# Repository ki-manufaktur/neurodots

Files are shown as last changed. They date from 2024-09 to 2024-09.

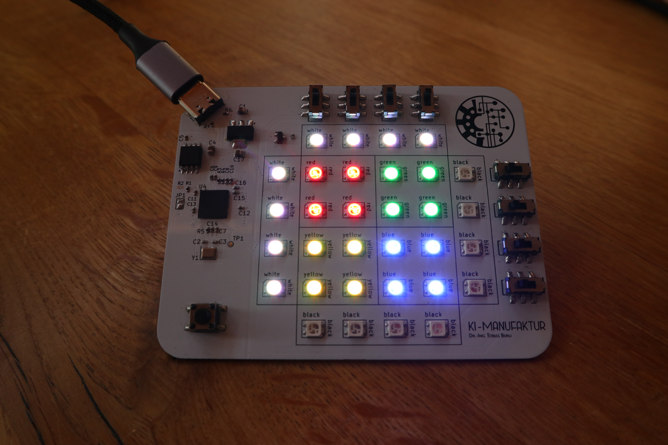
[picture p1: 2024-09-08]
doc/3.jpg

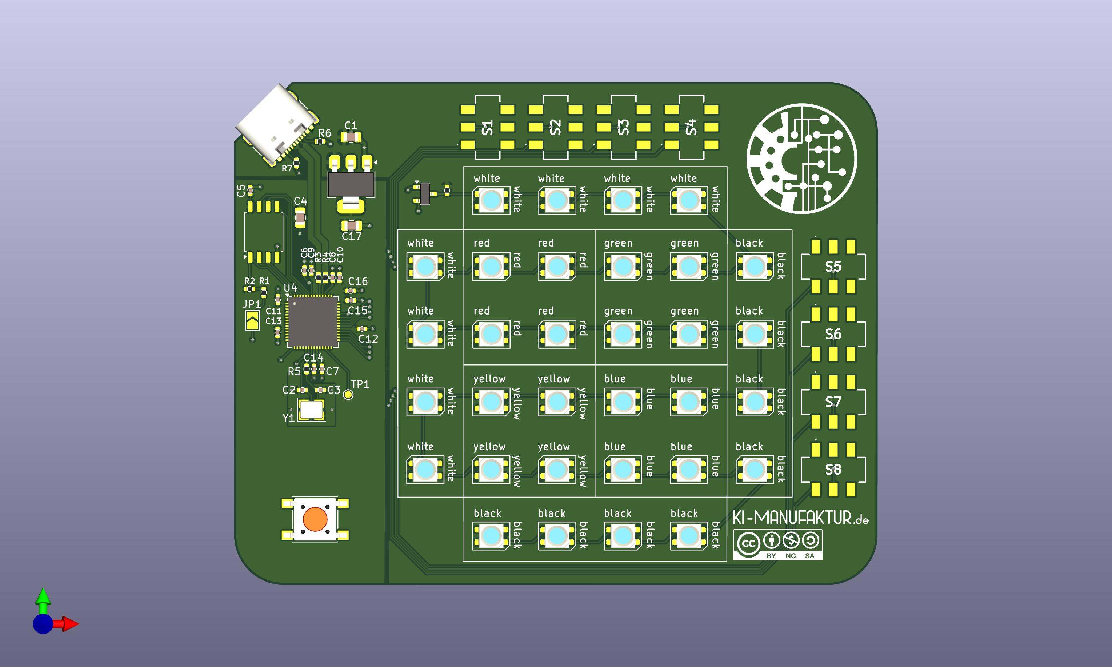
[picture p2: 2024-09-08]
doc/pcb.jpg

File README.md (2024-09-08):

# NEURODOTS

This project is inspired by the 3D printed [4x4 Colour Dot Puzzle](https://www.instructables.com/4x4-Colour-Dot-Puzzle/) by Sebastian Coddington and featured in Hackaday: [Color Dot Puzzle Will Wrinkle Your Brain](https://hackaday.com/2022/02/12/color-dot-puzzle-will-wrinkle-your-brain/).

Neurodots is an electronic version of the color dot puzzle, utilizing a WS2812 RGB maze. The dots are shifted horizontally or vertically using switches on the sides of the maze to guide the dots into the solution configuration.

In addition to the core gameplay of solving the puzzle, the project includes a feature that displays solution hints, generated by a neural network running on the RP2040 using TensorFlow Lite for Microcontrollers (TFLM). This demonstrates an intriguing application of a small neural network, as the theoretical number of possible game states is approximately 1.19e+16.

Storing a recommended move for all these states would be far beyond the storage capacity of an embedded device, even with clever compression techniques. Moreover, even if storage wasn’t an issue, determining a near-optimal move to solve the puzzle is a non-trivial task. This challenge also applies to heuristic algorithms running on the device.

Thus, the training objective of the neural network was to find a policy that solves the puzzle using the minimum number of moves. By quantizing and deploying this model in the TFLM environment, solutions are generated in real-time, with a response time of approximately 1.4 seconds from state change to recommendation.

## Usage

https://github.com/user-attachments/assets/8f202e22-c553-46a4-99aa-1d21afb3c0ef

1. **Starting the Game**: Press the push button to start a new game. The LED matrix will display a shuffled maze according to the configured difficulty level.
2. **Interacting with the Game**: Use the slide switches to toggle the paths of the maze.
3. **Hints**: If you need help, press the push button to see the next move, as suggested by the device’s AI, on the LED matrix.
4. **Finishing the Game**: The game will automatically detect when the puzzle has been solved and will display a completion animation on the LED matrix.

## Installation

1. Clone the repository and navigate to the project folder:

   ```bash
   git clone https://github.com/ki-manufaktur/neurodots.git
   cd neurodots
   ```

2. Build the project using CMake. Ensure you have exported the PICO_SDK_PATH environment variable before proceeding:

   ```bash
   export PICO_SDK_PATH=/path/to/pico-sdk
   mkdir build
   cd build
   cmake ..
   make
   ```

3. Flash the compiled binary to your Raspberry Pi Pico:

   * Bridge JP1 to enable flashing
   * Copy the neurodots.uf2 file to the RP2040 flash drive to complete the installation.

## Configuration

Brightness and Level Settings: Hold down the push button while turning on the device to adjust the brightness and difficulty level using the slide switches. The settings will be saved to flash memory for future sessions.

### Difficulty Level

The difficulty level can be set using the horizontally aligned switch row, as shown below:
   ```
+-------------------------------+
| [ X ]  [ S2 ]  [ S1 ]  [ S0 ] |
|          ↑1      ↓0      ↑1   |
+-------------------------------+
   ```

In this example, the switch configuration (with the rightmost switch being the least significant bit, LSB) represents a  
Difficulty Level = (1 × 2^2) + (0 × 2^1) + (1 × 2^0) = 5

### Brightness

config

Similar to the difficulty level, the brightness of the LEDs can be set using the vertically aligned switch column, as shown below:

```
+-----+
| S3  |  (No Function)
+-----+
| S2  |  ↑1
+-----+
| S1  |  ↑1
+-----+
| S0  |  ↓0  (LSB)
+-----+
```

Where in this configuration the brightness level is 6.

## Contributing

We welcome contributions! Feel free to open issues for bug reports, feature requests, or any suggestions to improve the game. You can also submit pull requests to add new features or enhance existing functionality. Please ensure to follow any contribution guidelines provided.

## License

This project is dual-licensed:

   * The software is licensed under the GNU General Public License v3.0 (GPLv3).
   * The PCB designs and schematics are licensed under the Creative Commons Attribution-NonCommercial-ShareAlike (CC BY-NC-SA) license.

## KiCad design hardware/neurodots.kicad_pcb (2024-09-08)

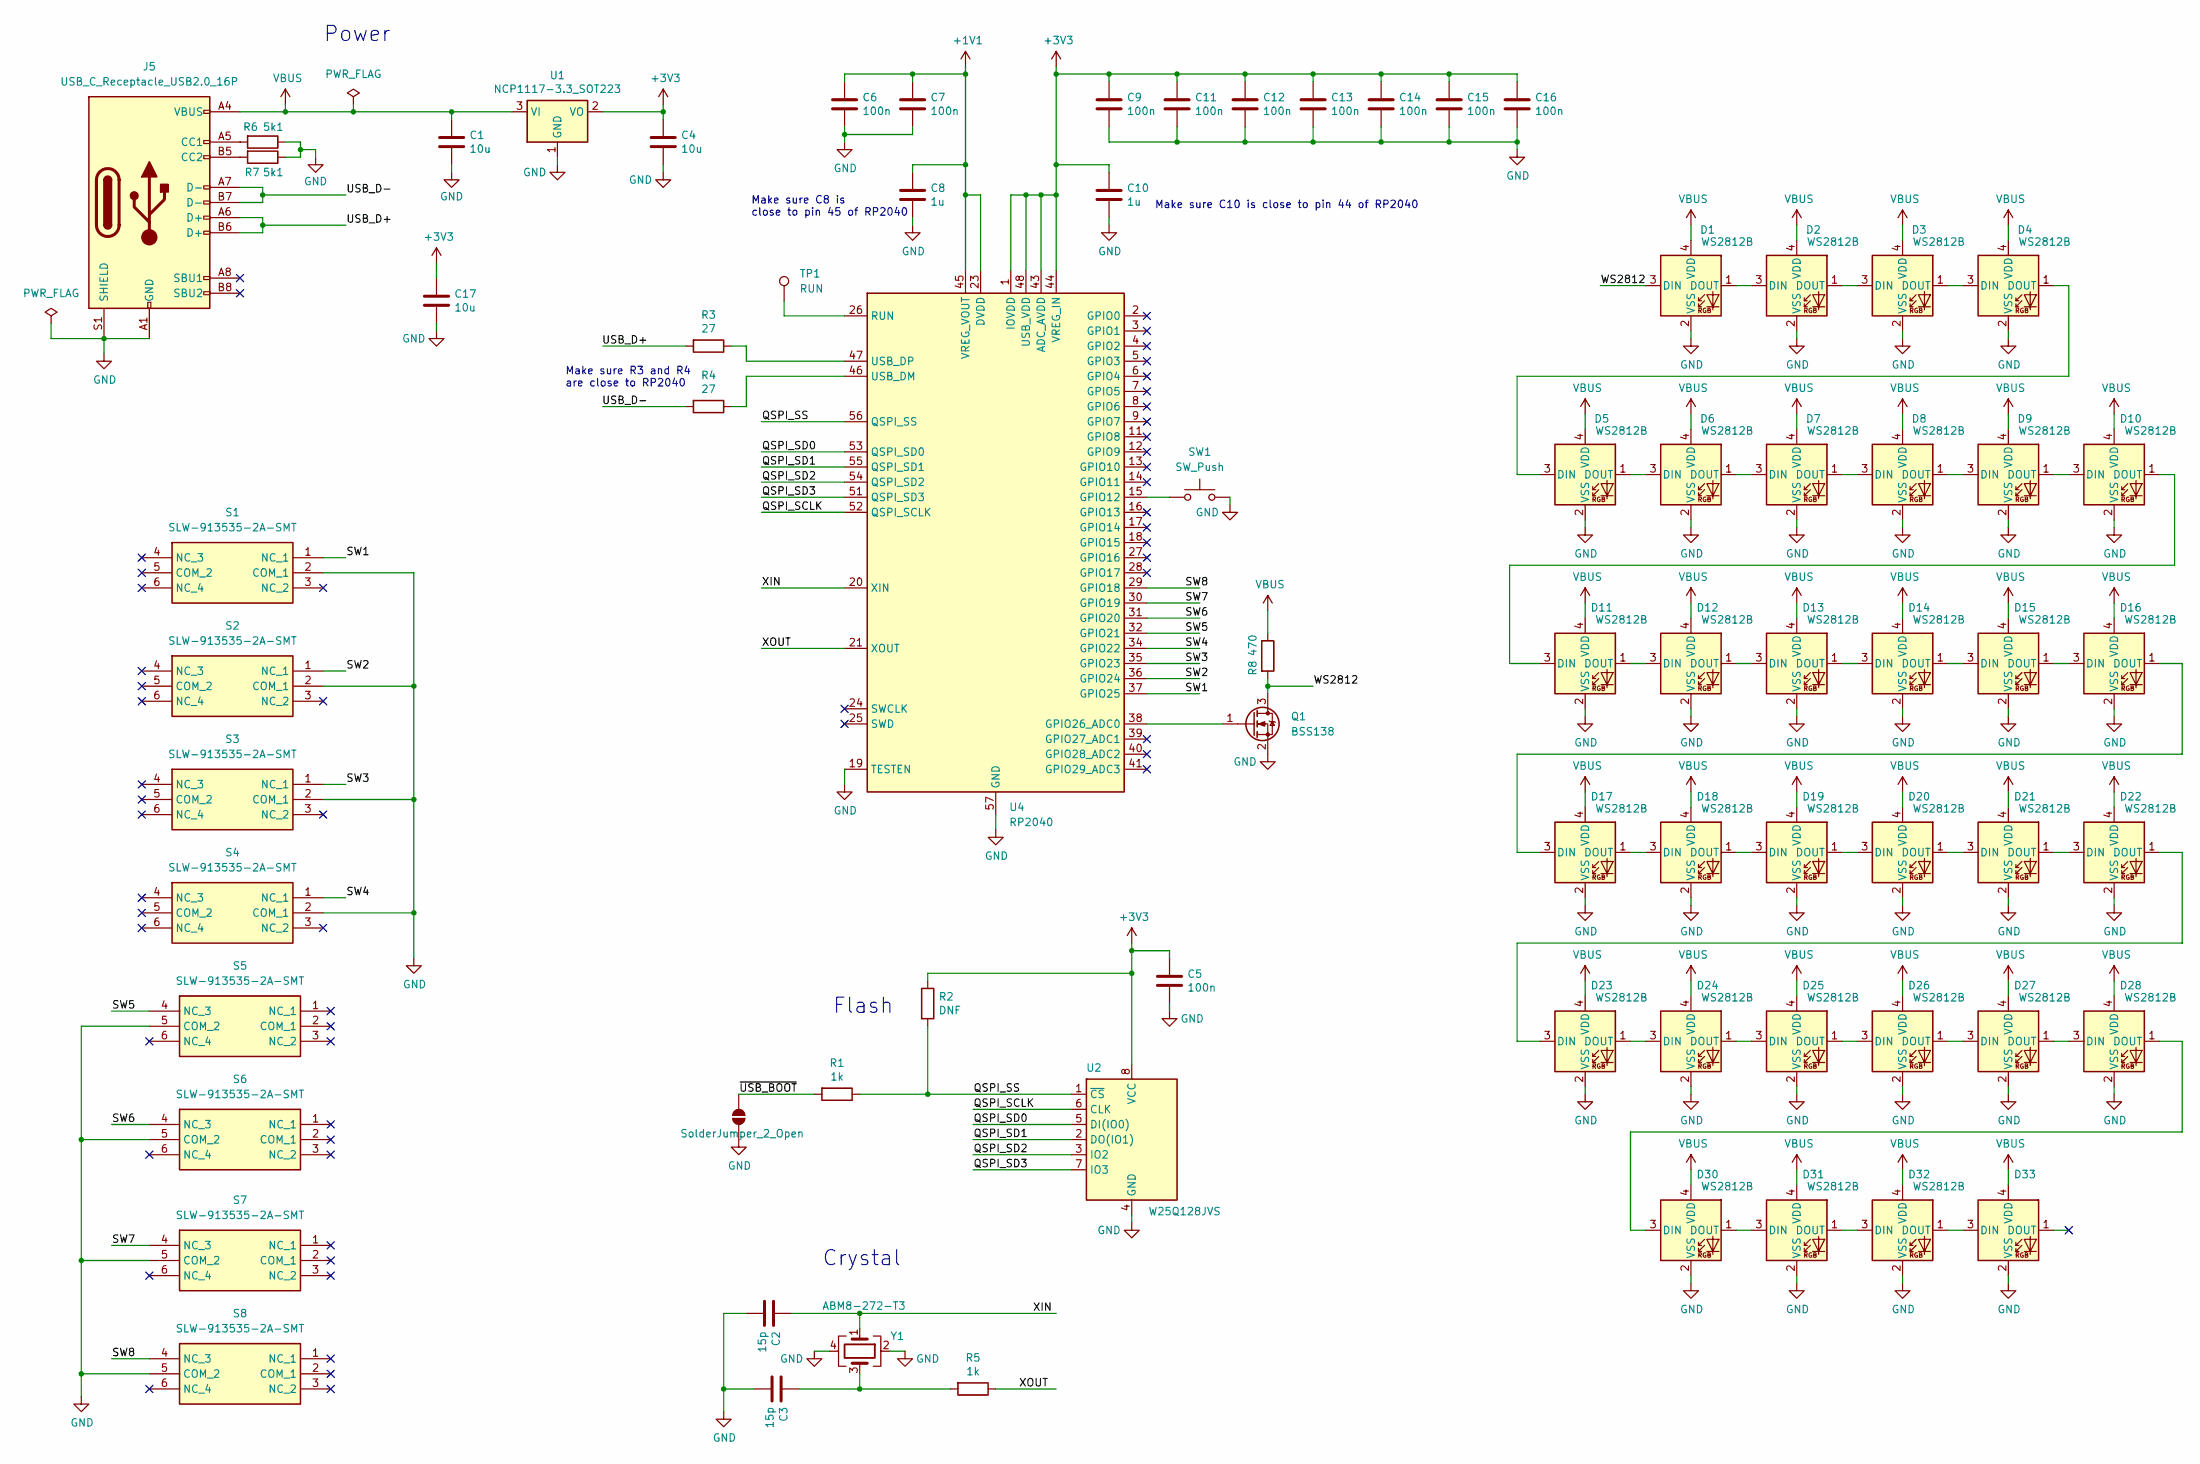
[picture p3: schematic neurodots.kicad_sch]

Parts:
C1, C4, C17: 10u; C_0805_2012Metric
C2, C3: 15p; C_0402_1005Metric
C5, C6, C7, C9, C11, C12, C13, C14, C15, C16: 100n; C_0402_1005Metric
C8, C10: 1u; C_0402_1005Metric
D1, D2, D3, D4, D5, D6, D7, D8, D9, D10, D11, D12, D13, D14, D15, D16, D17, D18, D19, D20, D21, D22, D23, D24, D25, D26, D27, D28, D30, D31, D32, D33: WS2812B; LED_WS2812B-Mini_PLCC4_3.5x3.5mm
J5: USB_C_Receptacle_USB2.0_16P; USB_C_Receptacle_GCT_USB4105-xx-A_16P_TopMnt_Horizontal
JP1: SolderJumper_2_Open; SolderJumper-2_P1.3mm_Open_TrianglePad1.0x1.5mm
Q1: BSS138; SOT-23
R1, R5: 1k; R_0402_1005Metric
R2: DNF; R_0402_1005Metric
R3, R4: 27; R_0402_1005Metric
R6, R7: 5k1; R_0402_1005Metric
R8: 470; R_0402_1005Metric
S1, S2, S3, S4, S5, S6, S7, S8: SLW-913535-2A-SMT; SLW9135352ASMT; Manufacturer_Part_Number SLW-913535-2A-SMT; Mouser Part Number 179-SLW-913535-2ASMT
SW1: SW_Push; SW_SPST_PTS645
TP1: RUN; TestPoint_Pad_D1.0mm
U1: NCP1117-3.3_SOT223; SOT-223-3_TabPin2
U2: W25Q128JVS; SOIC-8_5.23x5.23mm_P1.27mm
U4: RP2040; QFN-56-1EP_7x7mm_P0.4mm_EP3.2x3.2mm
Y1: ABM8-272-T3; Crystal_SMD_3225-4Pin_3.2x2.5mm

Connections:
+1V1: C6.1, C7.1, C8.1, U4.23 (DVDD), U4.45 (VREG_VOUT), U4.50 (DVDD)
+3V3: C4.1, C5.1, C9.1, C10.1, C11.1, C12.1, C13.1, C14.1, C15.1, C16.1, C17.1, R2.1, U1.2 (VO), U2.8 (VCC), U4.1 (IOVDD), U4.10 (IOVDD), U4.22 (IOVDD), U4.33 (IOVDD), U4.42 (IOVDD), U4.43 (ADC_AVDD), U4.44 (VREG_IN), U4.48 (USB_VDD), U4.49 (IOVDD)
/QSPI_SCLK: U2.6 (CLK), U4.52 (QSPI_SCLK)
/QSPI_SD0: U2.5 (DI(IO0)), U4.53 (QSPI_SD0)
/QSPI_SD1: U2.2 (DO(IO1)), U4.55 (QSPI_SD1)
/QSPI_SD2: U2.3 (IO2), U4.54 (QSPI_SD2)
/QSPI_SD3: U2.7 (IO3), U4.51 (QSPI_SD3)
/QSPI_SS: R1.1, R2.2, U2.1 (~CS), U4.56 (QSPI_SS)
/SW1: S1.1 (NC_1), U4.37 (GPIO25)
/SW2: S2.1 (NC_1), U4.36 (GPIO24)
/SW3: S3.1 (NC_1), U4.35 (GPIO23)
/SW4: S4.1 (NC_1), U4.34 (GPIO22)
/SW5: S5.4 (NC_3), U4.32 (GPIO21)
/SW6: S6.4 (NC_3), U4.31 (GPIO20)
/SW7: S7.4 (NC_3), U4.30 (GPIO19)
/SW8: S8.4 (NC_3), U4.29 (GPIO18)
/USB_D+: J5.A6 (D+), J5.B6 (D+), R3.2
/USB_D-: J5.A7 (D-), J5.B7 (D-), R4.2
/WS2812: D1.3 (DIN), Q1.3 (D), R8.2
/XIN: C2.1, U4.20 (XIN), Y1.1
/XOUT: R5.1, U4.21 (XOUT)
/~USB_BOOT: JP1.2 (B), R1.2
GND: C1.2, C2.2, C3.2, C4.2, C5.2, C6.2, C7.2, C8.2, C9.2, C10.2, C11.2, C12.2, C13.2, C14.2, C15.2, C16.2, C17.2, D1.2 (VSS), D2.2 (VSS), D3.2 (VSS), D4.2 (VSS), D5.2 (VSS), D6.2 (VSS), D7.2 (VSS), D8.2 (VSS), D9.2 (VSS), D10.2 (VSS), D11.2 (VSS), D12.2 (VSS), D13.2 (VSS), D14.2 (VSS), D15.2 (VSS), D16.2 (VSS), D17.2 (VSS), D18.2 (VSS), D19.2 (VSS), D20.2 (VSS), D21.2 (VSS), D22.2 (VSS), D23.2 (VSS), D24.2 (VSS), D25.2 (VSS), D26.2 (VSS), D27.2 (VSS), D28.2 (VSS), D30.2 (VSS), D31.2 (VSS), D32.2 (VSS), D33.2 (VSS), J5.A1 (GND), J5.A12 (GND), J5.B1 (GND), J5.B12 (GND), J5.S1 (SHIELD), JP1.1 (A), Q1.2 (S), R6.1, R7.1, S1.2 (COM_1), S2.2 (COM_1), S3.2 (COM_1), S4.2 (COM_1), S5.5 (COM_2), S6.5 (COM_2), S7.5 (COM_2), S8.5 (COM_2), SW1.2, U1.1 (GND), U2.4 (GND), U4.19 (TESTEN), U4.57 (GND), Y1.2, Y1.4
unnamed: C3.1, R5.2, Y1.3
unnamed: D1.1 (DOUT), D2.3 (DIN)
unnamed: D2.1 (DOUT), D3.3 (DIN)
unnamed: D3.1 (DOUT), D4.3 (DIN)
unnamed: D4.1 (DOUT), D5.3 (DIN)
unnamed: D5.1 (DOUT), D6.3 (DIN)
unnamed: D6.1 (DOUT), D7.3 (DIN)
unnamed: D7.1 (DOUT), D8.3 (DIN)
unnamed: D8.1 (DOUT), D9.3 (DIN)
unnamed: D9.1 (DOUT), D10.3 (DIN)
unnamed: D10.1 (DOUT), D11.3 (DIN)
unnamed: D11.1 (DOUT), D12.3 (DIN)
unnamed: D12.1 (DOUT), D13.3 (DIN)
unnamed: D13.1 (DOUT), D14.3 (DIN)
unnamed: D14.1 (DOUT), D15.3 (DIN)
unnamed: D15.1 (DOUT), D16.3 (DIN)
unnamed: D16.1 (DOUT), D17.3 (DIN)
unnamed: D17.1 (DOUT), D18.3 (DIN)
unnamed: D18.1 (DOUT), D19.3 (DIN)
unnamed: D19.1 (DOUT), D20.3 (DIN)
unnamed: D20.1 (DOUT), D21.3 (DIN)
unnamed: D21.1 (DOUT), D22.3 (DIN)
unnamed: D22.1 (DOUT), D23.3 (DIN)
unnamed: D23.1 (DOUT), D24.3 (DIN)
unnamed: D24.1 (DOUT), D25.3 (DIN)
unnamed: D25.1 (DOUT), D26.3 (DIN)
unnamed: D26.1 (DOUT), D27.3 (DIN)
unnamed: D27.1 (DOUT), D28.3 (DIN)
unnamed: D28.1 (DOUT), D30.3 (DIN)
unnamed: D30.1 (DOUT), D31.3 (DIN)
unnamed: D31.1 (DOUT), D32.3 (DIN)
unnamed: D32.1 (DOUT), D33.3 (DIN)
unnamed: J5.A5 (CC1), R6.2
unnamed: J5.B5 (CC2), R7.2
unnamed: Q1.1 (G), U4.38 (GPIO26_ADC0)
unnamed: SW1.1, U4.15 (GPIO12)
unnamed: TP1.1, U4.26 (RUN)
unnamed: R4.1, U4.46 (USB_DM)
unnamed: R3.1, U4.47 (USB_DP)
VBUS: C1.1, D1.4 (VDD), D2.4 (VDD), D3.4 (VDD), D4.4 (VDD), D5.4 (VDD), D6.4 (VDD), D7.4 (VDD), D8.4 (VDD), D9.4 (VDD), D10.4 (VDD), D11.4 (VDD), D12.4 (VDD), D13.4 (VDD), D14.4 (VDD), D15.4 (VDD), D16.4 (VDD), D17.4 (VDD), D18.4 (VDD), D19.4 (VDD), D20.4 (VDD), D21.4 (VDD), D22.4 (VDD), D23.4 (VDD), D24.4 (VDD), D25.4 (VDD), D26.4 (VDD), D27.4 (VDD), D28.4 (VDD), D30.4 (VDD), D31.4 (VDD), D32.4 (VDD), D33.4 (VDD), J5.A4 (VBUS), J5.A9 (VBUS), J5.B4 (VBUS), J5.B9 (VBUS), R8.1, U1.3 (VI)

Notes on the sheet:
Power
Crystal
Make sure C8 is close to pin 45 of RP2040
Make sure C10 is close to pin 44 of RP2040
Make sure R3 and R4 are close to RP2040
Flash

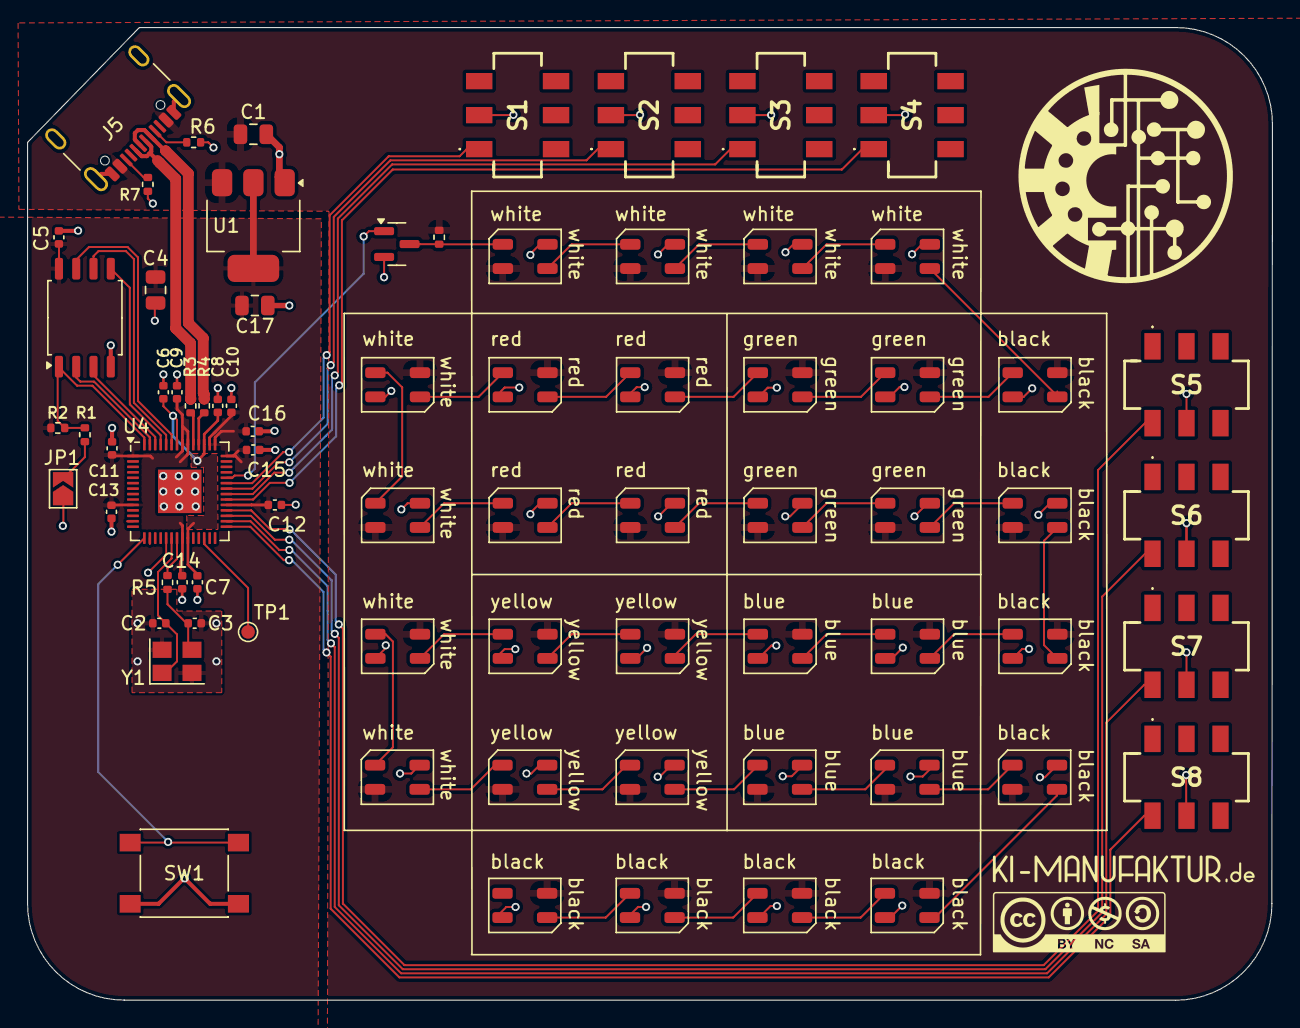
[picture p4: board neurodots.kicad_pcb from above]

Board: 2 copper layers, 91.5 x 71.5 mm, 74 parts (0 on the bottom side), 63 nets.

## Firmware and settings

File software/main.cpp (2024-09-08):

/* NEURODOTS
 * Copyright (C) 2024 ki-manufaktur.de
 *
 * This file is part of <your project name>.
 *
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
 * You should have received a copy of the GNU General Public License
 * along with this program.  If not, see <https://www.gnu.org/licenses/>.
 */

#include <cstdint>
#include <map>

#include "pico/stdlib.h"
#include "hardware/clocks.h"
#include "hardware/flash.h"
#include "hardware/sync.h"

#include "model_data.h"
#include "GpioMap.h"

#include "tensorflow/lite/micro/micro_interpreter.h"
#include "tensorflow/lite/micro/micro_log.h"
#include "tensorflow/lite/micro/micro_mutable_op_resolver.h"
#include "tensorflow/lite/micro/system_setup.h"
#include "tensorflow/lite/schema/schema_generated.h"

#include "game.h"
#include "display.h"

#define PUSHBUTTON_PIN 12
#define DEBOUNCE_TIME_US 150000
#define DEFAULT_BRIGTHNESS 8
#define DEFAULT_LEVEL 20

#define FLASH_TARGET_OFFSET (PICO_FLASH_SIZE_BYTES - FLASH_SECTOR_SIZE)

std::map<uint8_t, uint32_t> GpioMap;

volatile uint32_t timer_start = 0;
volatile uint32_t timer_stop = 0;

volatile bool game_started = false;
volatile bool game_finished = false;
volatile bool need_to_initialize = false;
volatile bool state_changed = false;
volatile bool display_hint = false;
volatile int8_t last_hint_switch = -1;

Game game = Game();
Display display = Display(DEFAULT_BRIGTHNESS);

void update_display()
{
    display.serialize_maze(game.maze);
    display.push_leds();
}

// Interrupt handler button / switch
void pin_callback(uint gpio, uint32_t events)
{
    if (gpio == PUSHBUTTON_PIN)
    {
        if (game_started == false)
        {
            // Initiates a new game by shuffling the dots, using a random seed based on the duration of the push button press
            // Start the timer on falling edge
            if (events & GPIO_IRQ_EDGE_FALL)
            {
                if ((time_us_32() - timer_start) > DEBOUNCE_TIME_US)
                {
                    timer_start = time_us_32();
                }
            }
            // Stop the timer on rising edge
            if ((events & GPIO_IRQ_EDGE_RISE) && ((time_us_32() - timer_start) > 1000))
            {
                // disable interrupt for this pin
                gpio_set_irq_enabled(PUSHBUTTON_PIN, GPIO_IRQ_EDGE_RISE | GPIO_IRQ_EDGE_FALL, false);
                timer_stop = time_us_32();

                // re-enable interrupt after DEBOUNCE_TIME_US
                add_alarm_in_us(DEBOUNCE_TIME_US, [](alarm_id_t id, void *user_data) -> int64_t
                                {
                                    uint gpio = (uint)(uintptr_t)user_data;

                                    // clear all queued interupts
                                    gpio_acknowledge_irq(gpio, GPIO_IRQ_EDGE_RISE | GPIO_IRQ_EDGE_FALL);
                                    // Re-enable the interrupt for this GPIO pin
                                    gpio_set_irq_enabled(gpio, GPIO_IRQ_EDGE_RISE | GPIO_IRQ_EDGE_FALL, true);

                                    return 0; // No need to call again
                                },
                                (void *)(uintptr_t)gpio, false);

                need_to_initialize = true;
                game_finished = false;
            }
        }
        else // if game started show hint
        {
            if (events & GPIO_IRQ_EDGE_RISE)
            {
                display_hint = true;
            }
        }
    }

    else
    { // slide switches changed
        // Disable further interrupts on this pin
        gpio_set_irq_enabled(gpio, GPIO_IRQ_EDGE_RISE | GPIO_IRQ_EDGE_FALL, false);

        // user choosed different switch than recommended by AI
        if (last_hint_switch != GpioMap[gpio])
        {
            last_hint_switch = -1;
        }

        game_finished = false;

        // update game
        game.toggle_switch(GpioMap[gpio]);
        update_display();

        // trigger new AI inference
        state_changed = true;

        // re-enable interrupt after DEBOUNCE_TIME_US
        add_alarm_in_us(DEBOUNCE_TIME_US, [](alarm_id_t id, void *user_data) -> int64_t
                        {
                            uint gpio = (uint)(uintptr_t)user_data;

                            // clear all queued interupts
                            gpio_acknowledge_irq(gpio, GPIO_IRQ_EDGE_RISE | GPIO_IRQ_EDGE_FALL);
                            // Re-enable the interrupt for this GPIO pin
                            gpio_set_irq_enabled(gpio, GPIO_IRQ_EDGE_RISE | GPIO_IRQ_EDGE_FALL, true);

                            return 0; // No need to call again
                        },
                        (void *)(uintptr_t)gpio, false);

        if ((game.check_finish() == true) && (game_started == true))
        {
            game_finished = true;
            game_started = false;
        }
    }
}

// tflite infrastructure
const tflite::Model *model = nullptr;
tflite::MicroInterpreter *interpreter = nullptr;
TfLiteTensor *input = nullptr;
TfLiteTensor *output = nullptr;

constexpr uint32_t kTensorArenaSize = 32000;
uint8_t tensor_arena[kTensorArenaSize];

int main()
{
    GpioMap[21] = 0;
    GpioMap[20] = 1;
    GpioMap[19] = 2;
    GpioMap[18] = 3;
    GpioMap[25] = 4;
    GpioMap[24] = 5;
    GpioMap[23] = 6;
    GpioMap[22] = 7;

    // Initialize serial port
    stdio_init_all();

    // Loop through GPIO 18 to 25 (slide switched) and set them as inputs with pull-ups
    for (uint8_t gpio = 18; gpio <= 25; gpio++)
    {
        gpio_init(gpio);             // Initialize the GPIO
        gpio_set_dir(gpio, GPIO_IN); // Set as input
        gpio_pull_up(gpio);          // Enable internal pull-up resistor
        sleep_us(10);
    }

    // Initialize PUSHBUTTON_PIN GPIO
    gpio_init(PUSHBUTTON_PIN);
    gpio_set_dir(PUSHBUTTON_PIN, GPIO_IN); // Set as input
    gpio_pull_up(PUSHBUTTON_PIN);          // Enable internal pull-up resistor
    sleep_us(10);

    // initialize ws2812 pio
    PIO pio = pio0;
    uint8_t sm = 0;
    uint32_t offset = pio_add_program(pio, &ws2812_program);
    ws2812_program_init(pio, sm, offset, WS2812_PIN, 800000, IS_RGBW);

    // read stored values for LED brightness and game difficulty
    uint32_t addr;
    int8_t page = FLASH_SECTOR_SIZE / FLASH_PAGE_SIZE - 1;
    uint8_t *p, brightness, difficulty;

    // flash wear protection
    while (page >= 0)
    {
        addr = XIP_BASE + FLASH_TARGET_OFFSET + (page * FLASH_PAGE_SIZE);
        p = (uint8_t *)addr;
        if (*p != 0xFF)
        {
            brightness = *p;
            difficulty = p[1];
            break;
        }
        page -= 1;
    }

    if (page == -1)
    {
        brightness = DEFAULT_BRIGTHNESS;
        difficulty = DEFAULT_LEVEL;
    }

    // check for pressed PUSHBUTTON_PIN during power-on to reinitialize brightness and game difficulty
    if (gpio_get(PUSHBUTTON_PIN) == 0)
    {
        uint8_t tmp_brightness = brightness;
        uint8_t tmp_difficulty = difficulty;
        while (gpio_get(PUSHBUTTON_PIN) == 0)
        {
            tmp_brightness = 1 << (gpio_get(20) * 4 + gpio_get(19) * 2 + gpio_get(18));
            // apply brightness
            display.update_brightness(tmp_brightness);
            update_display();

            tmp_difficulty = gpio_get(24) * 4 + gpio_get(23) * 2 + gpio_get(22);
            sleep_ms(100);
        }
        if ((tmp_brightness != brightness) || (tmp_difficulty != difficulty))
        {
            // store new parameters to flash
            page += 1;
            if (page == FLASH_SECTOR_SIZE / FLASH_PAGE_SIZE)
            // need to erase flash sector
            {
                uint32_t ints = save_and_disable_interrupts();
                flash_range_erase(FLASH_TARGET_OFFSET, FLASH_SECTOR_SIZE);
                restore_interrupts(ints);
                page = 0;
            }
            addr = XIP_BASE + FLASH_TARGET_OFFSET + (page * FLASH_PAGE_SIZE);
            p = (uint8_t *)addr;

            uint8_t buf[FLASH_PAGE_SIZE] = {0};
            buf[0] = tmp_brightness;
            buf[1] = tmp_difficulty;

            difficulty = tmp_difficulty;

            uint32_t ints = save_and_disable_interrupts();
            flash_range_program(FLASH_TARGET_OFFSET + (page * FLASH_PAGE_SIZE), (uint8_t *)buf, FLASH_PAGE_SIZE);
            restore_interrupts(ints);
        }
    }
    else
    {
        display.update_brightness(brightness);
        update_display();
    }

    // adapt game.switches to actual switch posiitons
    for (uint8_t gpio = 18; gpio < 22; gpio++)
    {
        if (game.switches[GpioMap[gpio]] != gpio_get(gpio))
        {
            sleep_ms(300);
            game.toggle_switch(GpioMap[gpio]);
            update_display();
        }
    }
    for (uint8_t gpio = 22; gpio < 26; gpio++)
    {
        if (game.switches[GpioMap[gpio]] == gpio_get(gpio))
        {
            sleep_ms(300);
            game.toggle_switch(GpioMap[gpio]);
            update_display();
        }
    }

    // enabel interrupts
    for (uint32_t gpio = 18; gpio <= 25; gpio++)
    {
        gpio_set_irq_enabled_with_callback(gpio, GPIO_IRQ_EDGE_RISE | GPIO_IRQ_EDGE_FALL, true, &pin_callback);
    }
    gpio_set_irq_enabled_with_callback(PUSHBUTTON_PIN, GPIO_IRQ_EDGE_RISE | GPIO_IRQ_EDGE_FALL, true, &pin_callback);

    // set up tflite model
    tflite::InitializeTarget();

    // Map the model into a usable data structure. This doesn't involve any
    // copying or parsing, it's a very lightweight operation.
    model = tflite::GetModel(colordot_q_tfl_tflite);

    if (model->version() != TFLITE_SCHEMA_VERSION)
    {
        printf(
            "Model provided is schema version %d not equal "
            "to supported version %d. \n",
            model->version(), TFLITE_SCHEMA_VERSION);
    }

    static tflite::MicroMutableOpResolver<11> resolver;
    TfLiteStatus resolve_status = resolver.AddFullyConnected();
    resolve_status = resolver.AddReshape();
    resolve_status = resolver.AddGatherNd();
    resolve_status = resolver.AddSub();
    resolve_status = resolver.AddSlice();
    resolve_status = resolver.AddConv2D();
    resolve_status = resolver.AddTranspose();
    resolve_status = resolver.AddPad();
    resolve_status = resolver.AddConcatenation();
    resolve_status = resolver.AddMaxPool2D();
    resolve_status = resolver.AddAdd();

    if (resolve_status != kTfLiteOk)
    {
        printf("Op resolution failed \n");
    }

    // Build an interpreter to run the model with.
    static tflite::MicroInterpreter static_interpreter(
        model, resolver, tensor_arena, kTensorArenaSize);
    interpreter = &static_interpreter;

    // Allocate memory from the tensor_arena for the model's tensors.
    TfLiteStatus allocate_status = interpreter->AllocateTensors();
    if (allocate_status != kTfLiteOk)
    {
        printf("AllocateTensors() failed \n");
    }

    // Obtain pointers to the model's input and output tensors.
    input = interpreter->input(0);
    output = interpreter->output(0);

    uint8_t hint_switch = 0;
    int8_t max_score = -127;

    state_changed = true;

    // Loop forever
    while (true)
    {
        if (need_to_initialize == true)
        {
            // Initiates a new game by shuffling the dots, using a random seed based on the duration of the push button press
            game.shuffle_dots(difficulty, timer_stop - timer_start);
            update_display();
            need_to_initialize = false;
            game_started = true;
            state_changed = true;
        }

        if (game_finished == true)
        {
            // play effect
            sleep_ms(200);
            display.off();
            display.push_leds();
            sleep_ms(150);
            display.serialize_maze_inner(game.maze);
            display.push_leds();
            sleep_ms(150);
            display.serialize_maze_middle(game.maze);
            display.push_leds();
            sleep_ms(150);
            display.serialize_maze(game.maze);
            display.push_leds();
            sleep_ms(200);
        }

        if ((state_changed == true) && (game_finished == false))
        {
            // start a new model inference
            state_changed = false;

            // prepare input
            for (uint8_t i = 0; i < 36; i++)
            {
                input->data.i32[i] = game.maze[i / 6][i % 6];
            }

            TfLiteStatus invoke_status = interpreter->Invoke();

            // get argmax on the output
            max_score = -128;
            for (uint8_t i = 0; i < 8; i++)
            {
                if ((output->data.int8[i] > max_score) && (i != last_hint_switch))
                {
                    max_score = output->data.int8[i];
                    hint_switch = i;
                }
            }
            last_hint_switch = hint_switch;
        }

        if (display_hint == true)
        {
            // display AI recommondation
            if (hint_switch < 4)
            {
                display.serialize_maze_hide_row(game.maze, hint_switch + 1);
            }
            else
            {
                display.serialize_maze_hide_col(game.maze, hint_switch - 3);
            }
            display.push_leds();
            sleep_ms(250);
            update_display();
            display_hint = false;
        }
        sleep_ms(10);
    }
}

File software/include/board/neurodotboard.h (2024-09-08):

#ifndef _NEUROSOTBOARD_PICO_H
#define _NEUROSOTBOARD_PICO_H

// For board detection
#define RASPBERRYPI_PICO

// --- UART ---
#ifndef PICO_DEFAULT_UART
#define PICO_DEFAULT_UART 0
#endif
#ifndef PICO_DEFAULT_UART_TX_PIN
#define PICO_DEFAULT_UART_TX_PIN 0
#endif
#ifndef PICO_DEFAULT_UART_RX_PIN
#define PICO_DEFAULT_UART_RX_PIN 1
#endif

// --- I2C ---
#ifndef PICO_DEFAULT_I2C
#define PICO_DEFAULT_I2C 0
#endif
#ifndef PICO_DEFAULT_I2C_SDA_PIN
#define PICO_DEFAULT_I2C_SDA_PIN 4
#endif
#ifndef PICO_DEFAULT_I2C_SCL_PIN
#define PICO_DEFAULT_I2C_SCL_PIN 5
#endif

// --- SPI ---
#ifndef PICO_DEFAULT_SPI
#define PICO_DEFAULT_SPI 0
#endif
#ifndef PICO_DEFAULT_SPI_SCK_PIN
#define PICO_DEFAULT_SPI_SCK_PIN 18
#endif
#ifndef PICO_DEFAULT_SPI_TX_PIN
#define PICO_DEFAULT_SPI_TX_PIN 19
#endif
#ifndef PICO_DEFAULT_SPI_RX_PIN
#define PICO_DEFAULT_SPI_RX_PIN 16
#endif
#ifndef PICO_DEFAULT_SPI_CSN_PIN
#define PICO_DEFAULT_SPI_CSN_PIN 17
#endif

// --- FLASH ---

#define PICO_BOOT_STAGE2_CHOOSE_W25Q080 1

#ifndef PICO_FLASH_SPI_CLKDIV
#define PICO_FLASH_SPI_CLKDIV 2
#endif

#define PICO_FLASH_SIZE_BYTES (16 * 1024 * 1024)

// Drive high to force power supply into PWM mode (lower ripple on 3V3 at light loads)
#define PICO_SMPS_MODE_PIN 23

#ifndef PICO_RP2040_B0_SUPPORTED
#define PICO_RP2040_B0_SUPPORTED 1
#endif

// The GPIO Pin used to read VBUS to determine if the device is battery powered.
#ifndef PICO_VBUS_PIN
#define PICO_VBUS_PIN 24
#endif

// The GPIO Pin used to monitor VSYS. Typically you would use this with ADC.
// There is an example in adc/read_vsys in pico-examples.
#ifndef PICO_VSYS_PIN
#define PICO_VSYS_PIN 29
#endif

#endif

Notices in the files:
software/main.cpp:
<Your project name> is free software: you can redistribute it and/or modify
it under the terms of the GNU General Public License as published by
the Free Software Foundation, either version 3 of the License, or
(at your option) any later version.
